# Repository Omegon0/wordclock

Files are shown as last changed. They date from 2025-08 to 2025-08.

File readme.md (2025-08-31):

# Quarter Past Five

This is a small 16x16 word clock that can tell the time with a minute resolution. It uses a Xiao RP2040 with four daisy-chained MAX7219 as the display with four key switches to set the time. Breakout pins for connecting a DS3231 RTC are included as well. Has a photoresistor for automatic light adjustment.

### Why?

Because reading the time in words gives me a sense of urgency that reading numbers does not. It makes me get things done more effectively. 

### Building instructions

Obtain parts labeled in the BOM. See either the table below. 

| Component | Identifier | Price | Amazon link |
|---|---|---|---|
| Xiao RP2040 | XIAO-RP2040 | $9.99 | [Amazon](https://www.amazon.com/Microcontroller-Dual-Core-MicroPython-CircuitPython-Interfaces/dp/B09NNVNW7M/)|
| DS3231 | RTC | $12.99 | [Amazon](https://www.amazon.com/HiLetgo-AT24C32-Arduino-Without-Battery/dp/B00LX3V7F0/)|
| Switches | switches | $10.99*4 | [Amazon](https://www.amazon.com/Mciepny-Waterproof-Dustproof-Pre-Lubricated-Mechanical/dp/B0FF9MBBDR?th=1)|
| MAX7219 | led-matrix | $8.28 | [Amazon](https://www.amazon.com/3PCS-MAX7219-Matrix-Display-Module/dp/B0FB99TY1Z/)|
| Photoresistor | photoresistor  | $7.39 | [Amazon](https://www.amazon.com/HiLetgo-Dependent-Photoresistor-Photoconductive-Resistance/dp/B00N1ZJUN4/)|
| CR2032 | N/A(separate)  | $3.97 | [Amazon](https://www.amazon.com/Amazon-Basics-CR2032-Compatible-Mercury-Free/dp/B0787K2XWZ/)|

Solder each component into the PCB accordingly, or follow the schematic to wire the pieces together. If using the PCB, make sure that things go the right direction. When soldering the MAX7219, solder the board with the LEDs first and then solder that to the PCB, not the other way around. It's a lot easier.

### Images

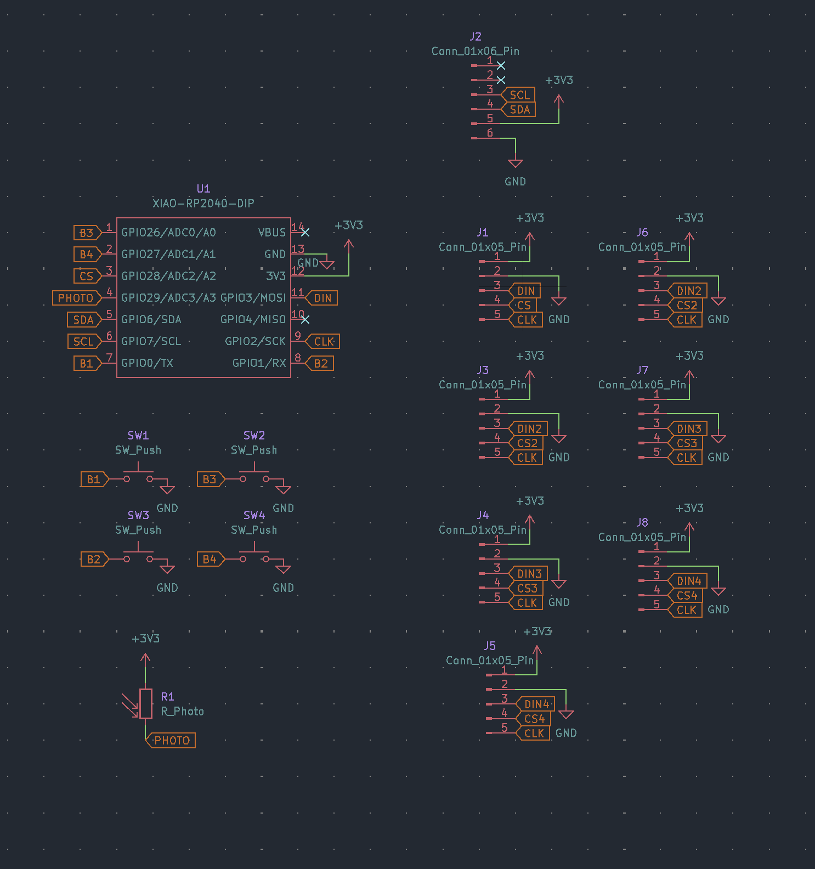
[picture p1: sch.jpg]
sch

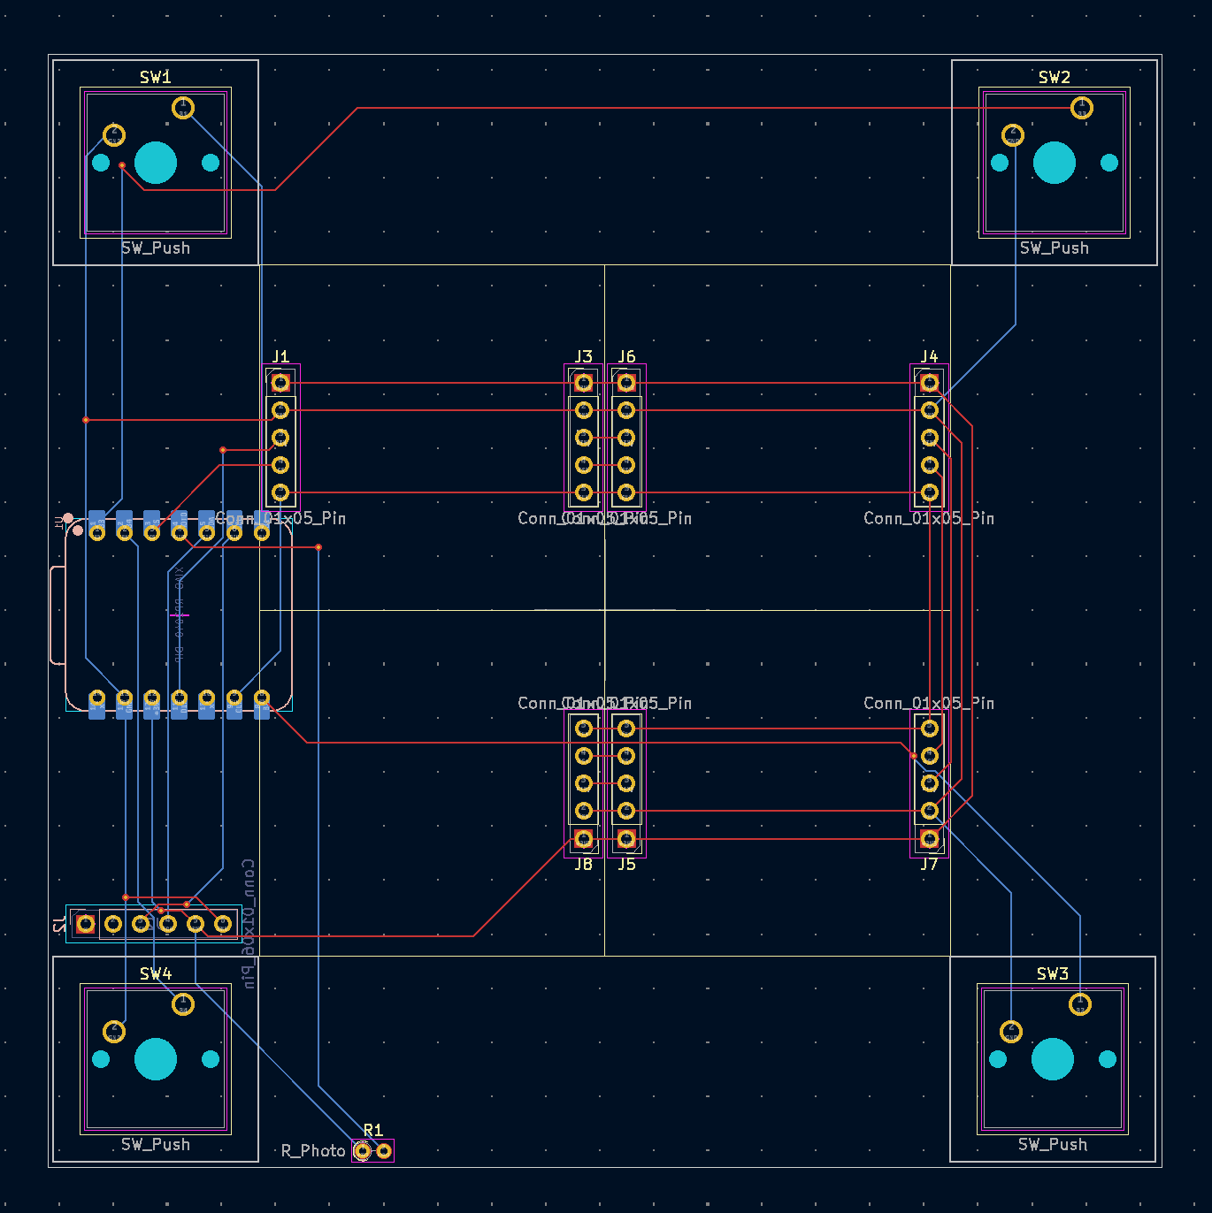
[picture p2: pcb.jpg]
pcb

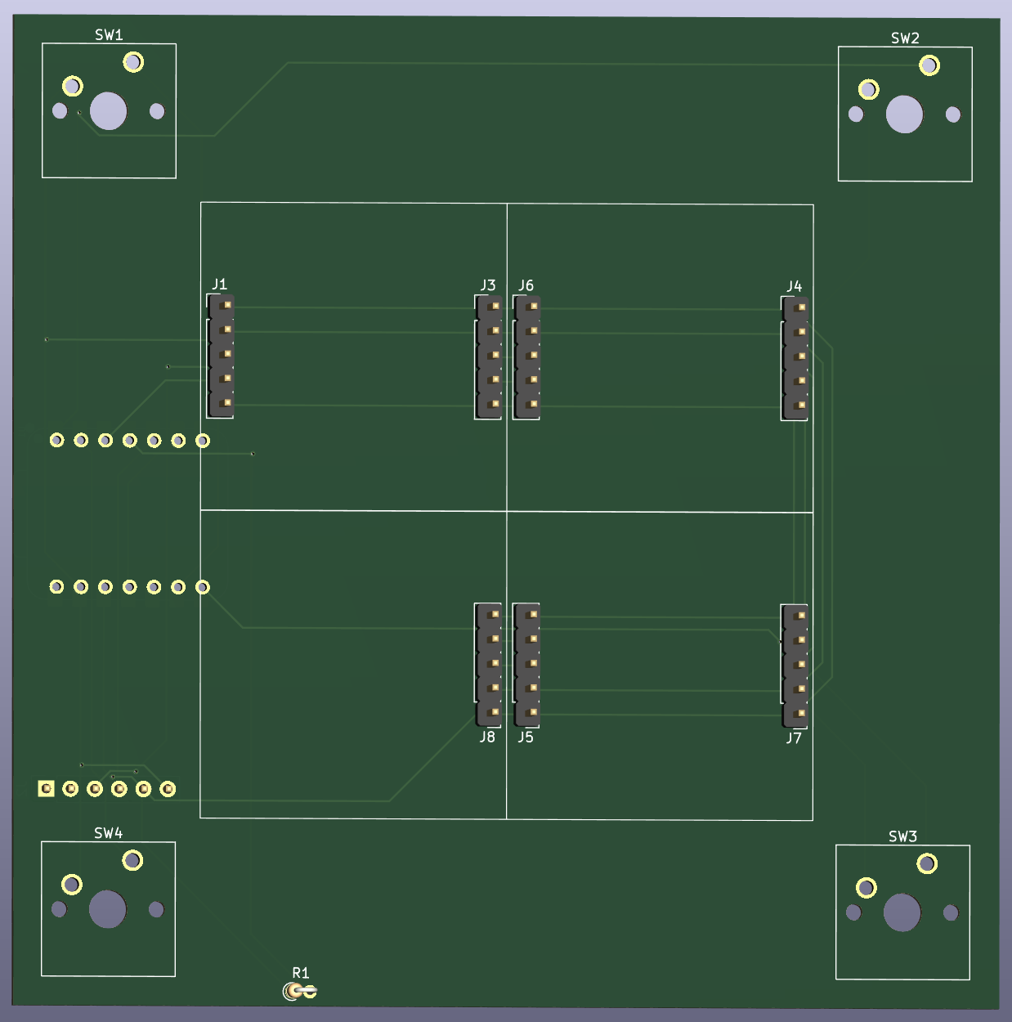
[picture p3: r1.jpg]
r1

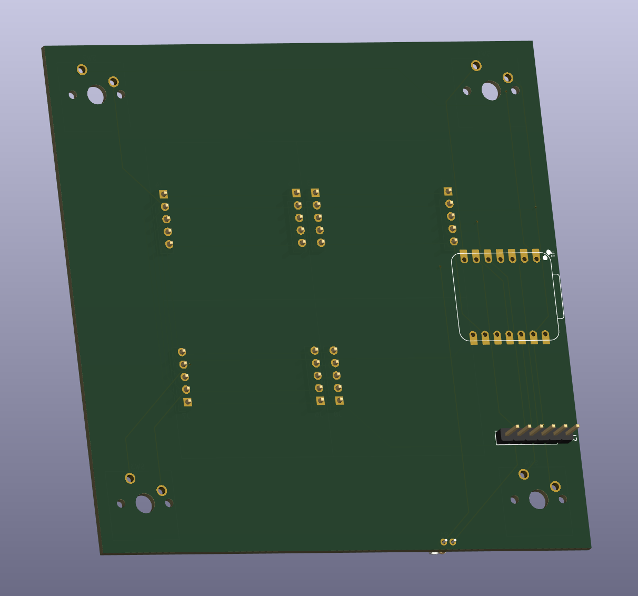
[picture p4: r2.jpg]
r2


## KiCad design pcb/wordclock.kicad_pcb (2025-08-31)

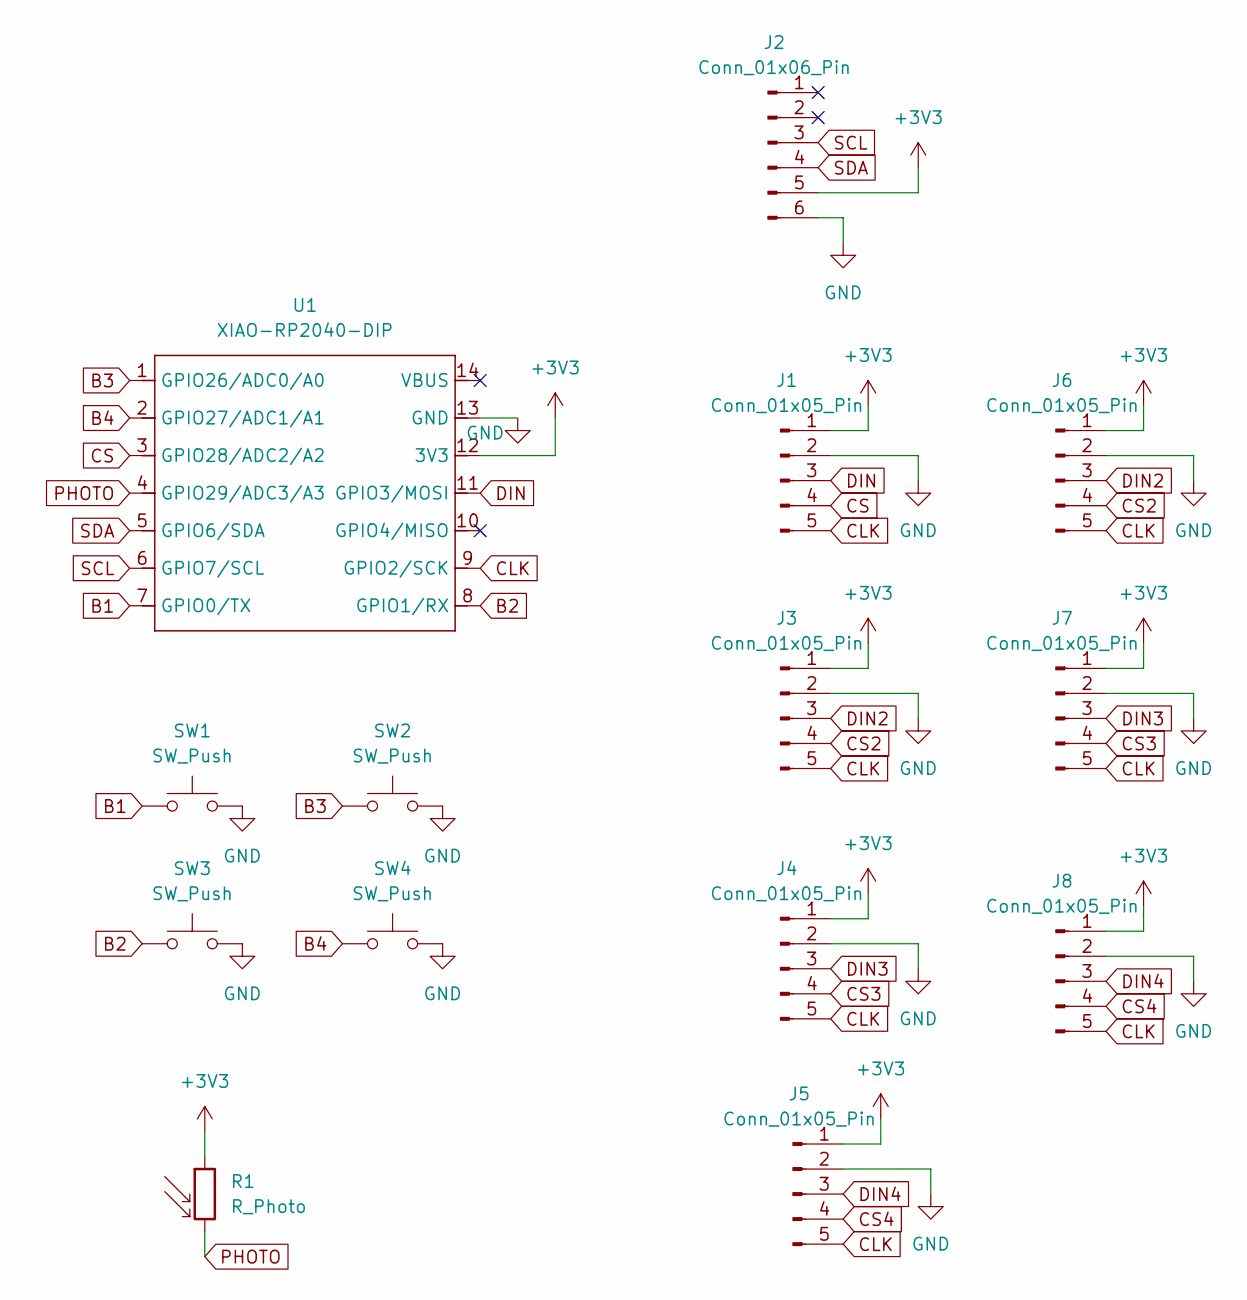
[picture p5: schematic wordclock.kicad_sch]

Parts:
J1, J3, J4, J5, J6, J7, J8: Conn_01x05_Pin; PinHeader_1x05_P2.54mm_Vertical
J2: Conn_01x06_Pin; PinHeader_1x06_P2.54mm_Vertical
R1: R_Photo; R_Axial_DIN0204_L3.6mm_D1.6mm_P1.90mm_Vertical
SW1, SW2, SW3, SW4: SW_Push; SW_Cherry_MX_1.00u_PCB
U1: XIAO-RP2040-DIP

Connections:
+3V3: J1.1, J2.5, J3.1, J4.1, J5.1, J6.1, J7.1, J8.1, R1.1, U1.12 (3V3)
B1: SW1.1, U1.7 (GPIO0/TX)
B2: SW3.1, U1.8 (GPIO1/RX)
B3: SW2.1, U1.1 (GPIO26/ADC0/A0)
B4: SW4.1, U1.2 (GPIO27/ADC1/A1)
CLK: J1.5, J3.5, J4.5, J5.5, J6.5, J7.5, J8.5, U1.9 (GPIO2/SCK)
CS: J1.4, U1.3 (GPIO28/ADC2/A2)
CS2: J3.4, J6.4
CS3: J4.4, J7.4
CS4: J5.4, J8.4
DIN: J1.3, U1.11 (GPIO3/MOSI)
DIN2: J3.3, J6.3
DIN3: J4.3, J7.3
DIN4: J5.3, J8.3
GND: J1.2, J2.6, J3.2, J4.2, J5.2, J6.2, J7.2, J8.2, SW1.2, SW2.2, SW3.2, SW4.2, U1.13 (GND)
PHOTO: R1.2, U1.4 (GPIO29/ADC3/A3)
SCL: J2.3, U1.6 (GPIO7/SCL)
SDA: J2.4, U1.5 (GPIO6/SDA)

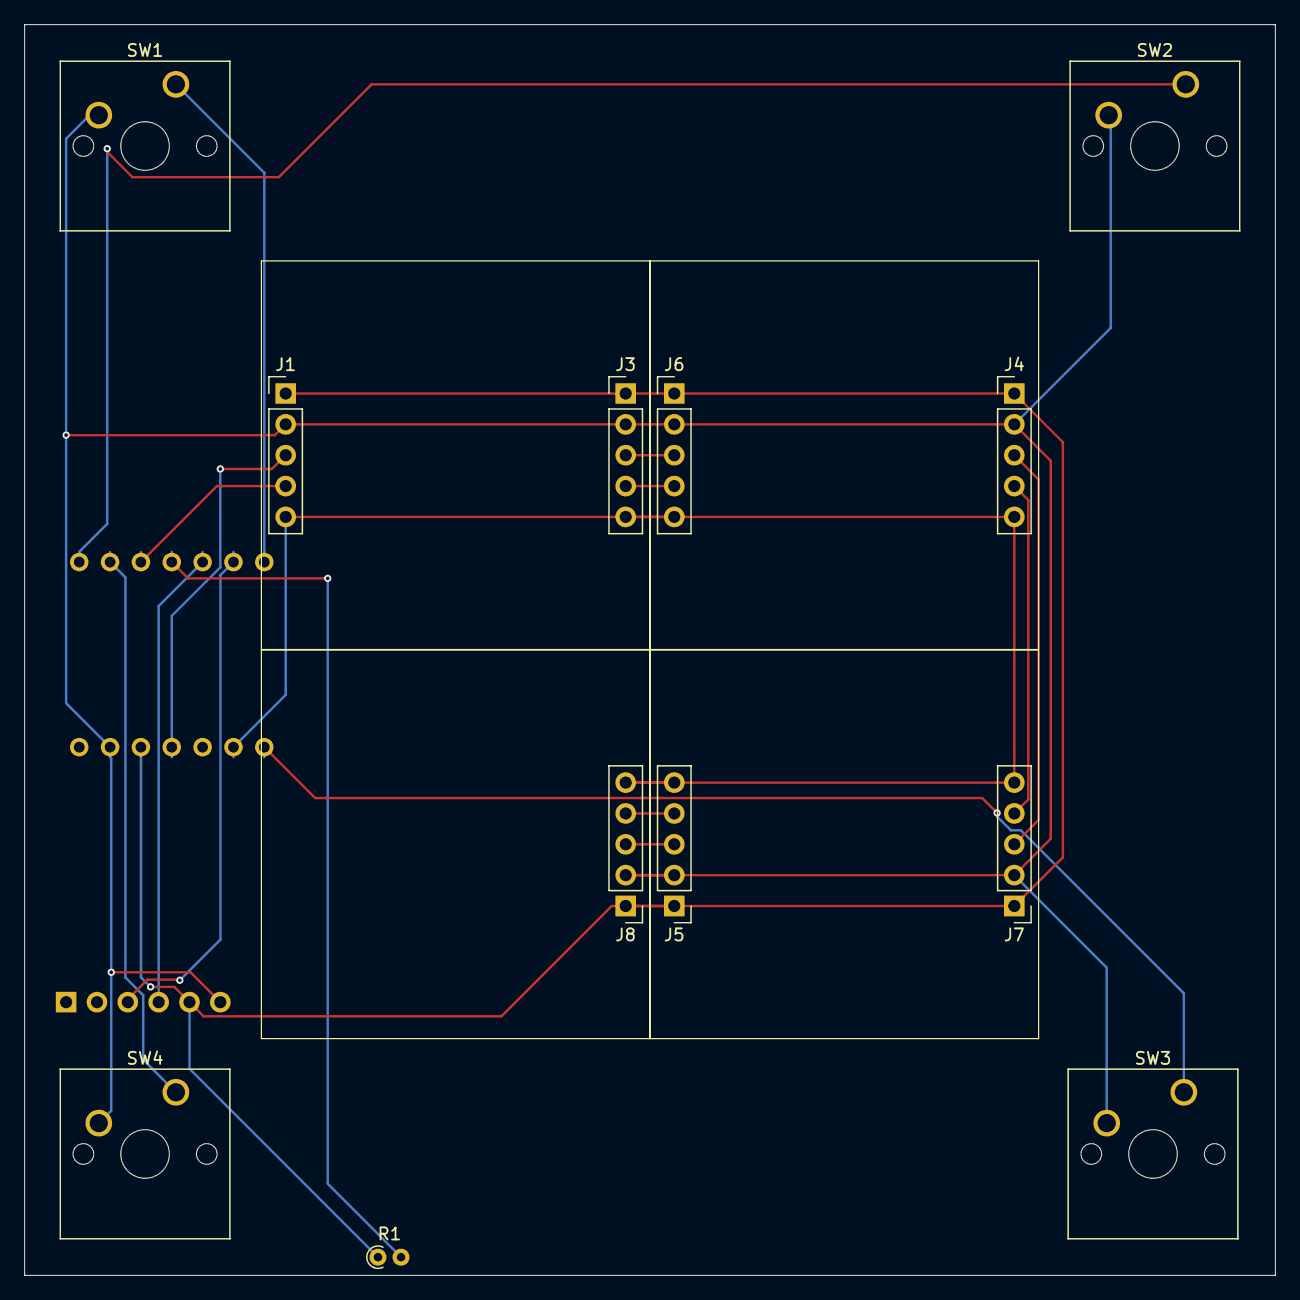
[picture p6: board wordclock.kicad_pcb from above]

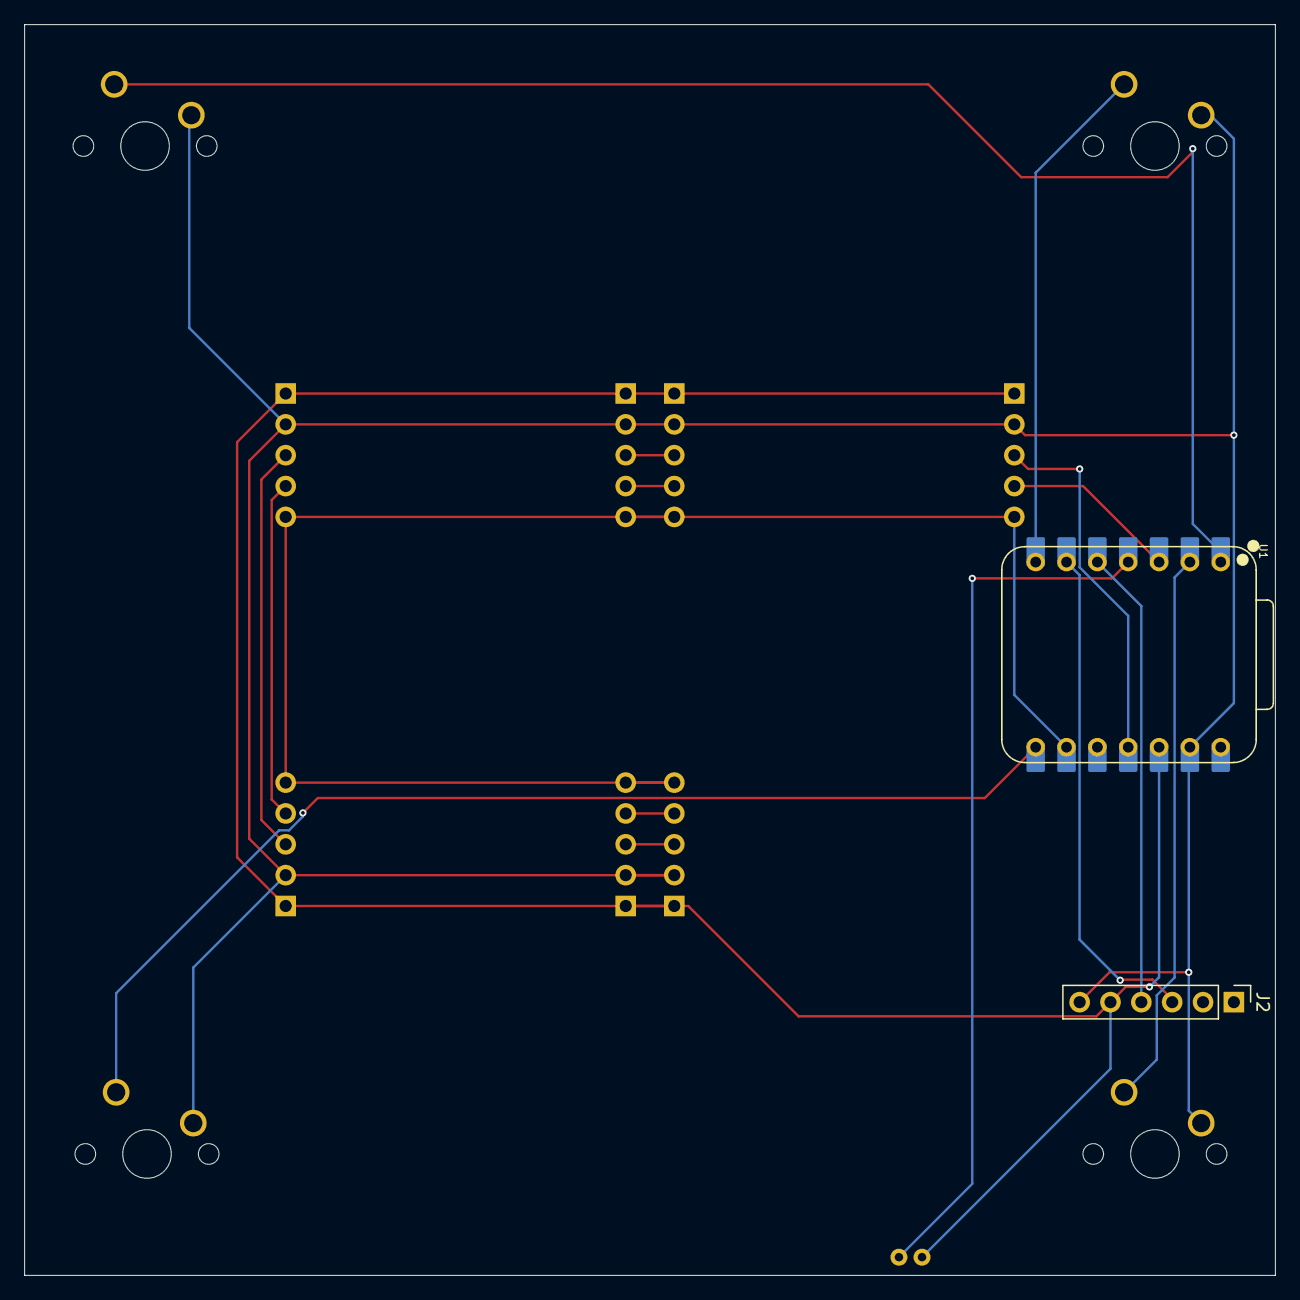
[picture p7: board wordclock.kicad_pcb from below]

Board: 2 copper layers, 103.0 x 103.0 mm, 14 parts (2 on the bottom side), 18 nets.

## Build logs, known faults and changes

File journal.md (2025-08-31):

---
Title: "Quarter Past Five"
Author: "Padimo"
Description: "Word Clock with minute level precision"
Created On: "8/12/2025"
---

# Day 1

Created the schematic based on the Xiao RP2040. Read MAX7219 datasheet to understand daisy chaining of multiple matrices.
Implemented daisy chaining for easier programming. 
Then I realized that I don't need a separate CS for everything and even those can be chained! modified as such. 



*time spent: 3h*

# Day 2

Autorouting broke so I had to route by hand. Created mental layout first and then added other components afterwards. 

Then I came up with the idea to add a photoresistor for auto-brightness. Added to schematic and circuit board.

Rerouted the daisy chain for more straightforward wiring without crossing with vias. Bottom two matrices are upside down, so that will be updated in code. 



*time spent: 4h*

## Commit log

2025-08-31 added readme and journal
    [wordclock-B_Cu.gbr, wordclock-B_Mask.gbr, wordclock-B_Paste.gbr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]
2025-08-31 reorganized files
    [wordclock-B_Cu.gbr, wordclock-B_Mask.gbr, wordclock-B_Paste.gbr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]
